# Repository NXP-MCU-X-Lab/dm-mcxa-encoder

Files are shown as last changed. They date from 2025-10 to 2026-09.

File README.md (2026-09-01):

# NXP MCXA344 Dual-Track Inductive Encoder

> English | [中文](README.zh-CN.md)

Firmware for the HW_V2 dual-track inductive absolute encoder based on the NXP
MCXA344. It samples 16/15 Vernier tracks at 10 kHz and provides a native 16-bit
single-turn position through a 2.5 Mbit/s T-Format interface.

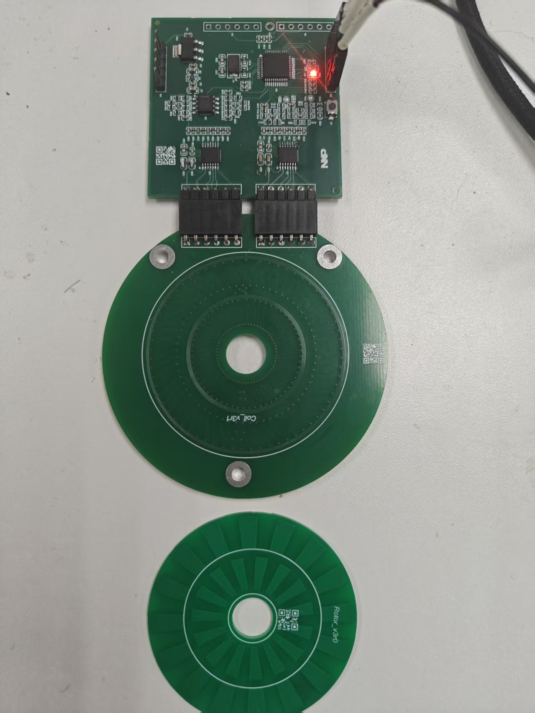
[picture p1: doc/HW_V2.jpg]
HW_V2 inductive encoder hardware


## Features

- 16/15 Vernier single-turn absolute-angle solver
- Native 16-bit position output (`0..65535` counts per revolution)
- Per-track offset, gain, quadrature, and ellipse correction
- Runtime center and gain adaptation with automatic persistence
- Branch validation, last-valid-position hold, and controlled re-lock
- Standard T-Format ID0/1/2/3/6/7/8/C/D responder on LPUART2/eDMA
- Persistent zero position and 762-byte paged encoder EEPROM image
- Compact FreeMASTER status and service page on LPUART0
- DWT execution profiling and dual-ADC sample-pair diagnostics

## Hardware

| Item | Configuration |
| --- | --- |
| MCU | NXP MCXA344VLL, Cortex-M33 with FPU, 180 MHz |
| Analog front end | MCXA OPAMP0/1 and external TLV9062 |
| Sampling | LPADC0/1, four channels, CTIMER0 trigger, 10 kHz |
| Persistent storage | Two 8 KB Flash sectors, 1024-byte snapshots, sequence and CRC32 |
| FreeMASTER | LPUART0, 115200 baud, 8N1 |
| T-Format | LPUART2, 2,500,000 baud, 8N1 |

### Signal Wiring

| Signal | MCU connection |
| --- | --- |
| A1 SIN | OPAMP0_OUT -> P2_15 (ADC0_A2) |
| A1 COS | OPAMP1_OUT -> P2_19 (ADC1_A2) |
| A2 SIN | TLV9062 output -> P2_6 (ADC1_A3) |
| A2 COS | TLV9062 output -> P2_7 (ADC0_A7) |
| T-Format TX | P2_2, LPUART2_TXD |
| T-Format RX | P2_3, LPUART2_RXD |
| RS-485 direction | P3_12, `DIR_485`; low for receive, high for transmit |
| Main-loop heartbeat | P3_11 |
| ADC ISR timing probe | P3_0 |

## Repository Layout

```text
source/
  app_adc.{h,c}              Synchronized dual-LPADC sampling
  app_encoder.{h,c}          Hardware-independent encoder algorithm
  app_encoder_runtime.{h,c}  Runtime adaptation, commands, and persistence
  app_encoder_storage.{h,c}  Dual-sector snapshots and CRC32
  app_encoder_defaults.c     Board default calibration
  app_tformat.{h,c}          T-Format responder on LPUART2/eDMA
  app_freemaster.{h,c}       FreeMASTER initialization and TSA table
  hardware_init.{h,c}        Clocks, OPAMP, pins, and utility GPIO

tools/
  tformat_test.py            Standard T-Format Python host

tests/
  encoder_sim.c              Algorithm and dynamic-profile simulation
  tformat_sim.c              Protocol vectors and state-machine tests
  storage_sim.c              Flash snapshot and power-loss injection tests
  stubs/                     Minimal MCU headers so app_tformat.c builds on the host

freemaster/
  index.html                 Compact operator and service page
  digital_encoder.pmpx       FreeMASTER desktop project
```

## Build and Flash

Install Keil MDK with ARMCLANG 6.23 and `NXP.MCXA344_DFP.25.06.00`. Open
`ind_encoder.uvprojx` and build target `ind_encoder`, or run:

```powershell
C:\Keil_v5\UV4\uVision.com -b ind_encoder.uvprojx -t ind_encoder -j0
```

The project targets `MCXA344VLL` and uses the `MCXA34X_256.FLM` download
algorithm. The application image is limited to `0x00000000..0x0003BFFF`.
`0x0003C000..0x0003FFFF` is reserved for persistent encoder data.

## T-Format Interface

The responder follows the public [NXP T-Format definitions](https://github.com/nxp-mcuxpresso/mcuxsdk-core/blob/release/26.03.00-pvw2/drivers/flexio/t-format/fsl_flexio_t-format.h)
and the field layout documented by the [TI T-Format reference design](https://www.ti.com/lit/ug/tidue74f/tidue74f.pdf).

| ID | CF | Function | Response length |
| --- | --- | --- | --- |
| ID0 | `0x02` | Single-turn position | 6 bytes |
| ID1 | `0x8A` | Multi-turn field, fixed to 0 | 6 bytes |
| ID2 | `0x92` | Encoder ID, `ENID=0x10` | 4 bytes |
| ID3 | `0x1A` | Position, ENID, ABM, and ALMC | 11 bytes |
| ID6 | `0x32` | EEPROM write | 4 bytes |
| ID7 | `0xBA` | Error reset | 6 bytes |
| ID8 | `0xC2` | Set and save single-turn zero | 6 bytes |
| IDC | `0x62` | Multi-turn reset acknowledgement; ABM remains 0 | 6 bytes |
| IDD | `0xEA` | EEPROM read | 4 bytes |

Every CF byte above is derived, not copied: `sink code 2 | (ID << 3) | (odd parity of
the ID bits << 7)`. Frame lengths, the ALMC bit map, the SF encoder-error field, the
ADF address/busy masks and the CRC polynomial all match the NXP definitions linked
above. `ENID` is the one value that does not come from a specification -- `0x10` is a
placeholder and must be agreed with the drive, since the resolution the drive infers
depends on it.

The UART is `2,500,000 baud, 8N1, idle high, LSB first`. `ABS0/ABS1` contain
the native 16-bit count and `ABS2=0`. Multi-turn fields are always zero. CRC uses
polynomial `x^8 + 1` with initial value 0. Invalid or stale position data is held
at the last valid value and reported as Counting Error through SF and ALMC.

`SF.ea0` reports Counting Error, `SF.ca0` reports a CF parity error, and
`SF.ca1` reports a UART delimiter error. `ALMC.CE` reports invalid or stale
position data and `ALMC.OS` reports speeds above 7200 rpm. Unsupported sensor
alarms remain zero. Communication errors are latched until a valid ID7 reset;
an active position fault is asserted again immediately.

ID7, ID8, and IDC execute after ten consecutive identical requests separated by
at least 40 us. ID8 saves the single-turn zero only when the shaft is stationary;
a rejected sequence reports Counting Error and is not deferred.

ADF address `0x7F` selects a volatile EEPROM page. Pages 0-5 each expose
127 persistent bytes (`0x00..0x7E`), for 762 bytes total. Pages 6 and 7 read as
`0xFF` and ignore writes. A data write keeps ADF busy until the new Flash
snapshot is verified; while busy, reads and writes return `EDF=0` and a second
write is rejected. Configuration writes require a stationary shaft. Unsupported
control fields and EEPROM CRC errors are silently ignored, and the protocol UART
emits no unsolicited text.

### Python Host

Install pyserial and replace `COM78` with the connected adapter:

```powershell
python -m pip install pyserial
python tools\tformat_test.py --self-test
python tools\tformat_test.py --port COM78 --data-id 0 --count 1000 --verbose
python tools\tformat_test.py --port COM78 --data-id 3 --count 1000
python tools\tformat_test.py --port COM78 --reset position
python tools\tformat_test.py --port COM78 --page 0 --eeprom-write 0x20 0xA5
python tools\tformat_test.py --port COM78 --page 0 --eeprom-read 0x20
python tools\tformat_test.py --port COM78 --page 0 --eeprom-read-page
python tools\tformat_test.py --port COM78 --eeprom-read-all
python tools\tformat_test.py --port COM78 --page 0 --eeprom-write-page page0.bin
```

`--reset` sends the required ten-frame sequence. A page image is a raw 127-byte
binary file; full-page writes skip unchanged bytes and verify the final page.

## Calibration and Operation

At startup, the latest valid Flash snapshot is loaded. If storage is empty, the
encoder starts from board defaults, adapts track centers and gains after adequate
rotational coverage, and saves the converged parameters after the shaft becomes
stationary. T-Format reports Counting Error until this initial adaptation locks.

`Zero & Save` and T-Format ID8 require the position to remain within 16 counts
for 0.5 seconds. The firmware averages 64 samples, changes the single-turn zero,
and confirms completion only after Flash verification.

The complete ellipse and quadrature calibration remains available in the
FreeMASTER Service section. It captures 8192 decimated samples while the shaft
is rotated through complete cycles, then saves the solved calibration and zero.

## FreeMASTER

Open `freemaster/digital_encoder.pmpx`, connect LPUART0 at 115200 baud, and open
the embedded web page. The main view contains readiness, angle, speed, status,
and `Zero & Save`. The collapsed Service section contains raw ADC values,
runtime counters, T-Format counters, factory calibration, and configuration
erase. The page polls primary status at approximately 4 Hz and does not use
Scope or Recorder.

## Configuration

| Macro | Value | Purpose |
| --- | --- | --- |
| `ADC_SAMPLE_RATE_HZ` | `10000` | Encoder update rate |
| `ENCODER_CAL_SAMPLE_COUNT` | `8192` | Service calibration samples |
| `ENCODER_TRACKING_BW_HZ` | `100.0f` | Observer bandwidth |
| `ENCODER_TRACKING_ZETA` | `0.707f` | Observer damping ratio |
| `ENCODER_FILTER_HOLD_RESYNC_SAMPLES` | `50` | Re-lock interval after invalid samples |
| `ENCODER_OUTPUT_DEADBAND_DEG` | `0.015f` | Monitoring-angle dead band |
| `ENCODER_ANGLE_COUNT_HYSTERESIS` | `3` | Low-latency count hysteresis |

## Notes

- The product interface is single-turn; ABM and all multi-turn fields are zero.
- The current storage version does not migrate older records. Run Factory Cal
  once after installing firmware that changes the persistent record version.
- Flash erase/program temporarily pauses sampling and T-Format responses.
- EEPROM and zero writes remain busy until the shaft is stationary and the new
  snapshot is verified.
- LPUART0 is reserved for FreeMASTER. DebugConsole and ordinary UART logs are
  not part of the product target.

## License

The project application code is provided under the BSD-3-Clause license; see
[LICENSE](LICENSE). Bundled SDK, CMSIS, and FreeMASTER components retain their
own copyright and license notices.

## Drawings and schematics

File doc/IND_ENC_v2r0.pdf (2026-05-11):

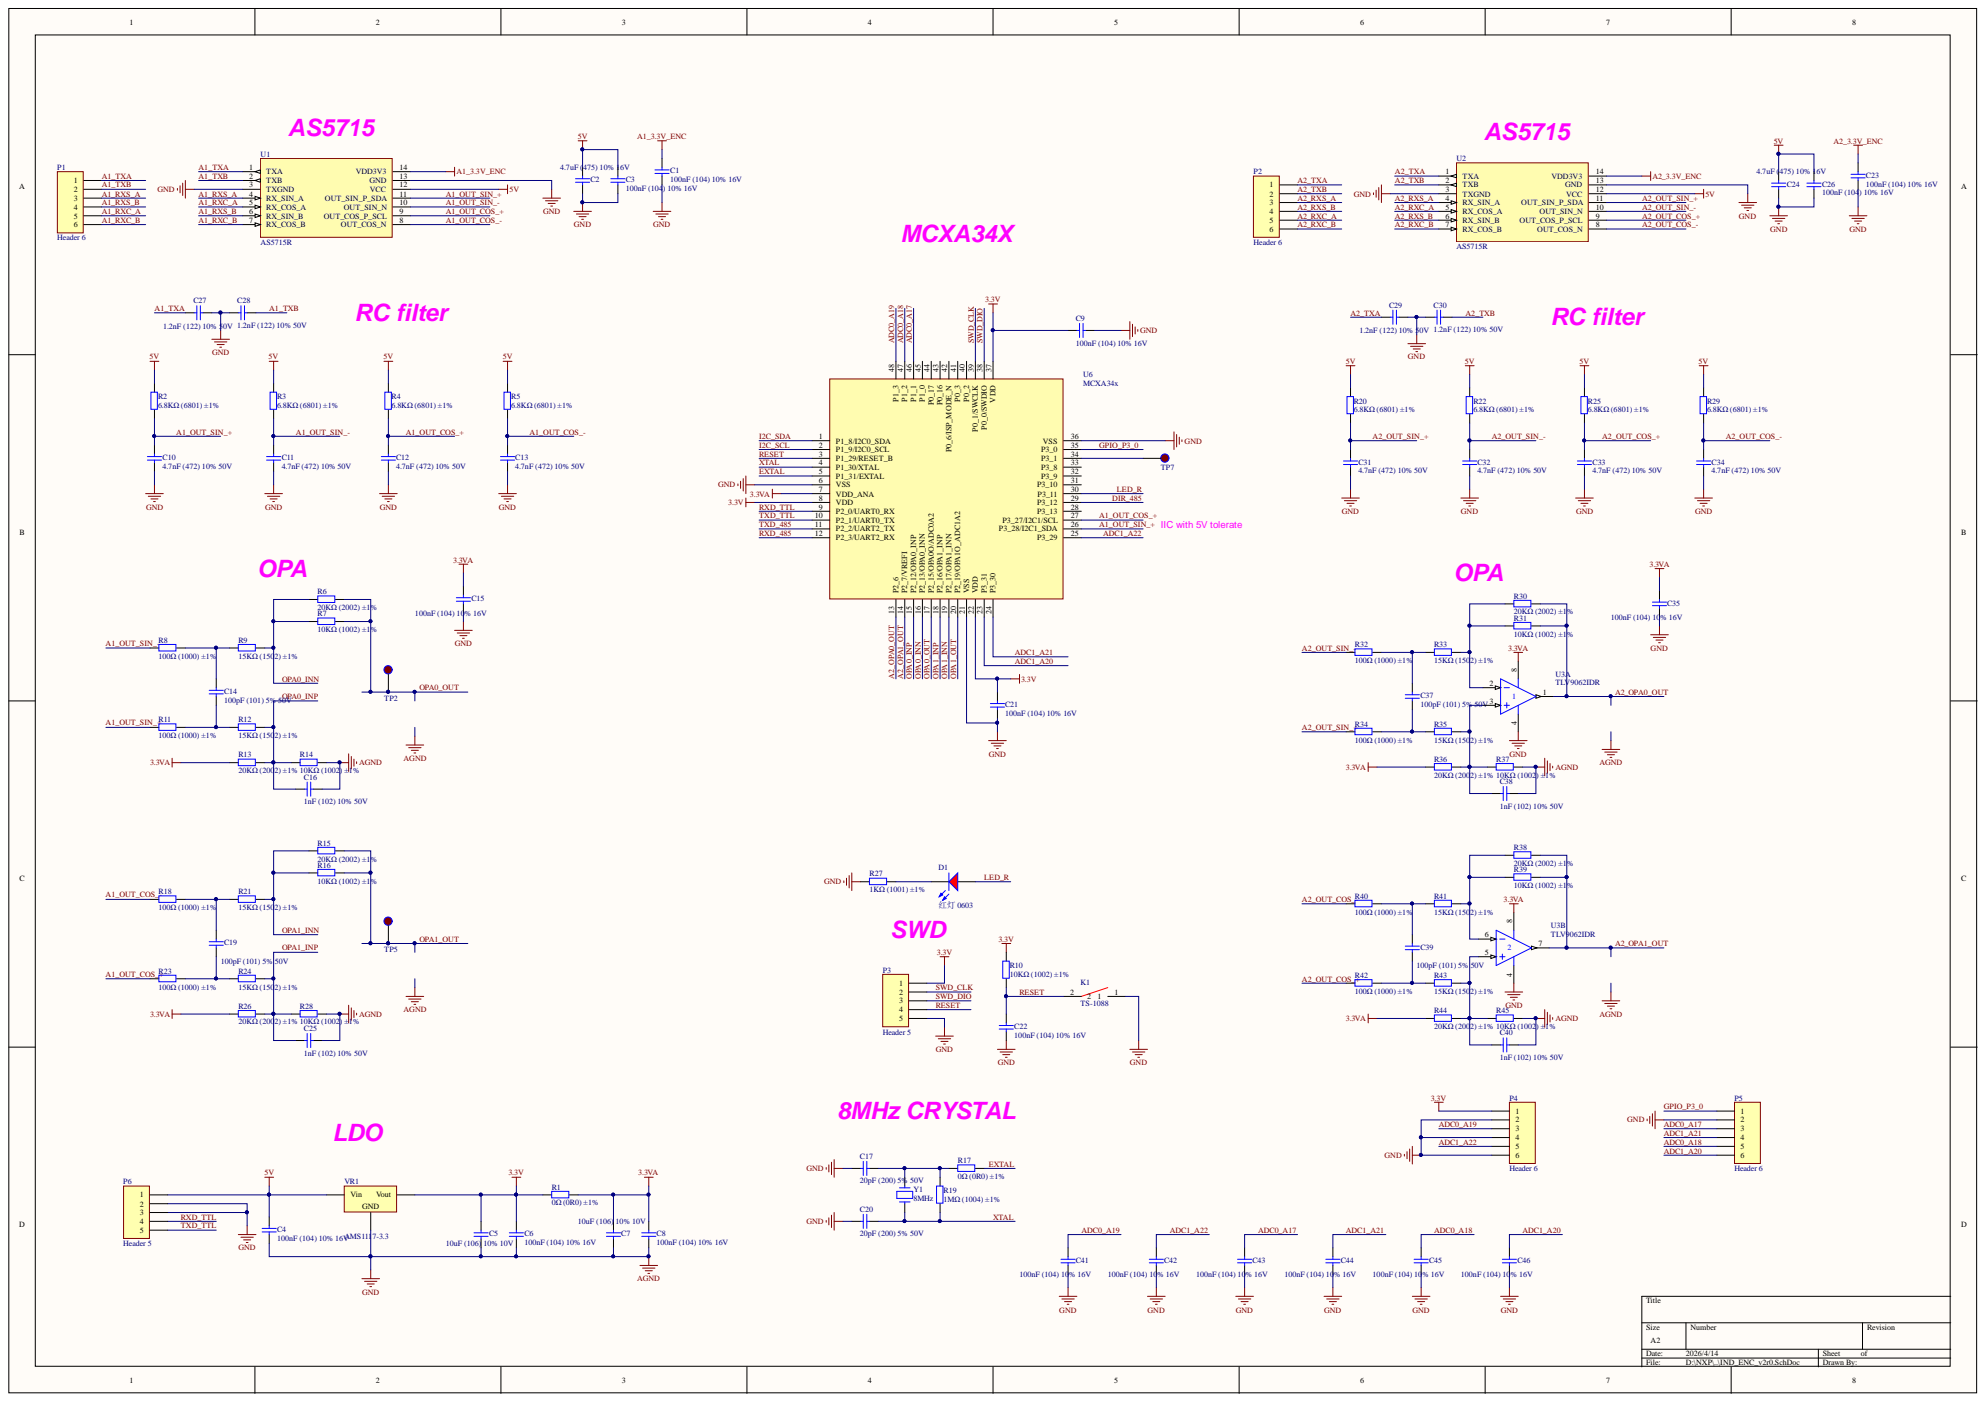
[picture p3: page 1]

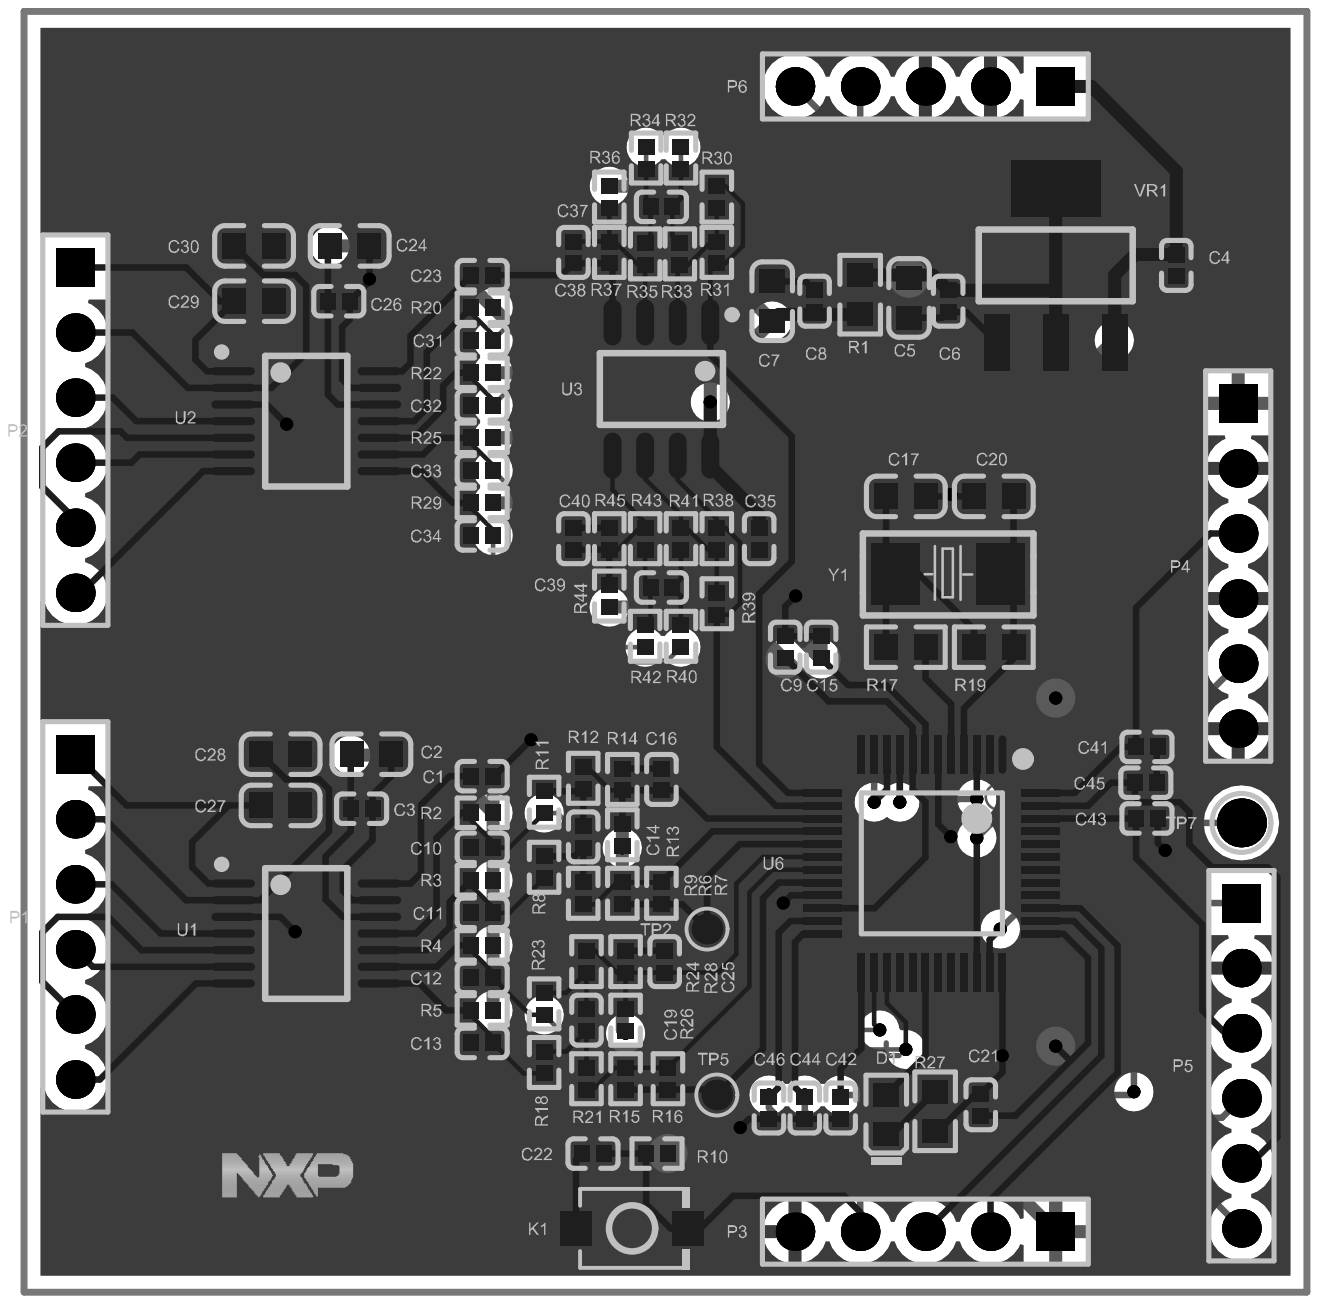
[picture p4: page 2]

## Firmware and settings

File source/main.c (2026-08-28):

/*
  * Copyright 2025 NXP
  *
  * SPDX-License-Identifier: BSD-3-Clause
  */

#include "fsl_common.h"

#include "app_adc.h"
#include "app_encoder_runtime.h"
#include "app_freemaster.h"
#include "app_tformat.h"
#include "freemaster.h"
#include "freemaster_cfg.h"
#include "freemaster_serial_lpuart.h"
#include "hardware_init.h"

static void run_main_loop(void)
{
    while (1)
    {
        EncoderApp_Service();
        FMSTR_Poll();
        Heartbeat_Service();
        __WFI();
    }
}

int main(void)
{
    Hardware_Init();
    adc_init();
    AppFreemaster_Init();
    TFormat_Init();
    EncoderApp_Init();

    run_main_loop();
}

#if FMSTR_SHORT_INTR || FMSTR_LONG_INTR

void LPUART0_IRQHandler(void)
{
    FMSTR_SerialIsr();
}

#endif

void HardFault_Handler(void)
{
    while (1)
    {
    }
}

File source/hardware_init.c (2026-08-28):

/*
  * Copyright 2025 NXP
  *
  * SPDX-License-Identifier: BSD-3-Clause
  */
/*${header:start}*/
#include "pin_mux.h"
#include "fsl_clock.h"
#include "fsl_reset.h"
#include "fsl_spc.h"
#include "fsl_opamp.h"
#include "fsl_gpio.h"
#include "fsl_port.h"
#include "fsl_mau.h"
#include "clock_config.h"
#include "hardware_init.h"
/*${header:end}*/





/* Test pin for ADC timing measurement (P3_0, driven low while ISR is busy) */
#define TEST_PIN_GPIO       GPIO3
#define TEST_PIN_PORT       PORT3
#define TEST_PIN_NUM        0U

#define HEARTBEAT_GPIO      GPIO3
#define HEARTBEAT_PORT      PORT3
#define HEARTBEAT_PIN       11U
#define HEARTBEAT_TOGGLE_INTERVAL_MS 100U

#define DEMO_OPAMP_COMP_CAP       kOPAMP_FitGain2x
#define DEMO_OPAMP_BIAS_CURRENT   kOPAMP_NoChange



/*! @brief Initialize TEST pin (P3_0) for ADC timing measurement */
void TestPin_Init(void)
{
    gpio_pin_config_t pin_config = {
        .pinDirection = kGPIO_DigitalOutput,
        .outputLogic = 1  /* Idle high; ISR drives low while busy */
    };

    PORT_SetPinMux(TEST_PIN_PORT, TEST_PIN_NUM, kPORT_MuxAsGpio);
    GPIO_PinInit(TEST_PIN_GPIO, TEST_PIN_NUM, &pin_config);
}

/* Free-running millisecond tick incremented by SysTick (configured @ 1 kHz).
 * Used by delay_ms() — independent of SDK_DelayAtLeastUs(), which has been
 * observed to skip its busy-wait on this part. */
volatile uint32_t g_systick_ms = 0U;

void Heartbeat_Init(void)
{
    gpio_pin_config_t pin_config = {
        .pinDirection = kGPIO_DigitalOutput,
        .outputLogic = 0
    };
    PORT_SetPinMux(HEARTBEAT_PORT, HEARTBEAT_PIN, kPORT_MuxAsGpio);
    GPIO_PinInit(HEARTBEAT_GPIO, HEARTBEAT_PIN, &pin_config);
    uint32_t core_hz = CLOCK_GetFreq(kCLOCK_CoreSysClk);
    SysTick_Config(core_hz / 1000U);
}

void SysTick_Handler(void)
{
    g_systick_ms++;
}

void Heartbeat_Service(void)
{
    static uint32_t last_toggle_ms;
    const uint32_t now = g_systick_ms;

    if ((uint32_t)(now - last_toggle_ms) >= HEARTBEAT_TOGGLE_INTERVAL_MS)
    {
        last_toggle_ms = now;
        GPIO_PortToggle(HEARTBEAT_GPIO, 1U << HEARTBEAT_PIN);
    }
}

void delay_ms(uint32_t ms)
{
    uint32_t t0 = g_systick_ms;
    while ((uint32_t)(g_systick_ms - t0) < ms)
    {
        /* spin */
    }
}

/*! @brief Configure OPAMP modules */
void Opamp_Init(void)
{
    opamp_config_t config;

    RESET_ReleasePeripheralReset(kOPAMP0_RST_SHIFT_RSTn);
    RESET_ReleasePeripheralReset(kOPAMP1_RST_SHIFT_RSTn);

    SPC_EnableActiveModeAnalogModules(SPC0, (kSPC_controlOpamp0 | kSPC_controlOpamp1));
    
    OPAMP_GetDefaultConfig(&config);
    config.compCap     = DEMO_OPAMP_COMP_CAP;
    config.biasCurrent = DEMO_OPAMP_BIAS_CURRENT;
    config.enable = true;
    
    OPAMP_Init(OPAMP0, &config);
    OPAMP_Init(OPAMP1, &config);
    
    OPAMP_Enable(OPAMP0, true);
    OPAMP_Enable(OPAMP1, true);
}

/*${function:start}*/
void Hardware_Init(void)
{
    Pins_Init();
    BOARD_InitBootClocks();
    Opamp_Init();
    TestPin_Init();
    Heartbeat_Init();
    
    mau_config_t cfg;
    MAU_GetDefaultConfig(&cfg);
    MAU_Init(MAU0, &cfg);
}

/*! @brief Set test pin to high level */
void TestPin_Set(void)
{
    GPIO_PinWrite(TEST_PIN_GPIO, TEST_PIN_NUM, 1U);
}

/*! @brief Set test pin to low level */
void TestPin_Clear(void)
{
    GPIO_PinWrite(TEST_PIN_GPIO, TEST_PIN_NUM, 0U);
}

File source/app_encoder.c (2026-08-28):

#include "app_encoder.h"
#include "app_adc.h"

#include <float.h>
#include <math.h>
#include <stddef.h>

#define ENCODER_PI (3.14159265358979323846f)
#define ENCODER_ADC_RAIL_LOW (64U)
#define ENCODER_ADC_RAIL_HIGH (65471U)
#define ENCODER_MIN_RAW_AMPLITUDE (256.0f)
#define ENCODER_MIN_NORMALIZED_MAG (0.15f)
#define ENCODER_TRACK_PHASE_TOLERANCE_DEG (45.0f)
#define ENCODER_DEFAULT_RAW_CENTER (32768.0f)
#define ENCODER_DEFAULT_RAW_AMPLITUDE (16384.0f)
#define ENCODER_FINE_BRANCH_STEP_DEG (360.0f / (float)ENCODER_TRACK16_CYCLES)
#define ENCODER_BRANCH_SLIP_STEP_DEG (0.5f * ENCODER_FINE_BRANCH_STEP_DEG)
#define ENCODER_BRANCH_ERROR_MARGIN_DEG (5.0f)
/* Acceptance band for trimming: exactly the set of magnitudes the gain authority
 * can still pull back to 1.0. Gain is multiplicative -- a delta d scales T by
 * (1 + d) -- so the band is not symmetric about 1.0. With a limit of L, a
 * magnitude m is correctable when 1/(1 + L) <= m <= 1/(1 - L).
 *
 * Getting this wrong in either direction is a trap. Narrower than the authority
 * (the original 0.75..1.25 against +/-0.5) leaves half of it unreachable: the
 * estimator switches itself off precisely when the amplitude has drifted far
 * enough to need it, and can never climb back. Wider than the authority admits
 * magnitudes it cannot fix, so the AGC parks against its clamp. The rail and
 * WEAK checks alongside are what actually reject unusable samples. */
#define ENCODER_RUNTIME_TRIM_MAG_MIN (1.0f / (1.0f + ENCODER_RUNTIME_TRIM_GAIN_TOTAL_LIMIT))
#define ENCODER_RUNTIME_TRIM_MAG_MAX (1.0f / (1.0f - ENCODER_RUNTIME_TRIM_GAIN_TOTAL_LIMIT))
#define ENCODER_RUNTIME_TRIM_BIN_COUNT (16U)
#define ENCODER_RUNTIME_TRIM_FULL_COVERAGE_MASK (0xFFFFUL)
#define ENCODER_RUNTIME_TRIM_MIN_WINDOW_SAMPLES (512U)
#define ENCODER_RUNTIME_TRIM_ALPHA (0.125f)
/* 5 s at 10 kHz. Long enough that ordinary rough running never re-acquires,
 * short enough that a board which locked on bad data heals itself instead of
 * needing a reflash. */
#define ENCODER_RUNTIME_TRIM_RELOCK_SAMPLES (50000U)
/* Windows that still take the measured centre outright rather than creeping.
 * The first lock is necessarily approximate -- harmonic distortion makes the
 * waveform asymmetric, so the min/max midpoint sits a few hundred counts off the
 * true centre even across whole cycles. Creeping that away at the drift step
 * limit would take hundreds of revolutions; a few more snap windows close it in
 * a few. Only once those are spent is the remaining error actually drift. */
#define ENCODER_RUNTIME_TRIM_SNAP_SOLVES (4U)

typedef struct _encoder_solver_candidate
{
    float p16;
    float p15;
    float coarse;
    float angle;
    float phase16_error;
    float phase15_error;
    float error;
} encoder_solver_candidate_t;

static bool is_finite_float(float value)
{
    return ((value == value) && (fabsf(value) < FLT_MAX));
}

static float wrap_deg(float deg)
{
    while (deg >= 360.0f)
    {
        deg -= 360.0f;
    }

    while (deg < 0.0f)
    {
        deg += 360.0f;
    }

    return deg;
}

static float signed_angle_error_deg(float actual, float expected)
{
    float diff = wrap_deg(actual - expected);

    if (diff > 180.0f)
    {
        diff -= 360.0f;
    }

    return diff;
}

static float max_float(float a, float b)
{
    return (a > b) ? a : b;
}

static uint32_t angle_to_counts(float angle_deg)
{
    uint32_t counts = (uint32_t)(((wrap_deg(angle_deg) * (float)ENCODER_COUNTS_PER_REV) / 360.0f) + 0.5f);

    if (counts >= ENCODER_COUNTS_PER_REV)
    {
        counts -= ENCODER_COUNTS_PER_REV;
    }

    return counts;
}

static float clamp_float(float value, float min_value, float max_value)
{
    if (value < min_value)
    {
        return min_value;
    }

    if (value > max_value)
    {
        return max_value;
    }

    return value;
}

/* Type-II tracking observer (software PLL) — canonical resolver / inductive
 * encoder output stage. Closed-loop characteristic eq: s^2 + Kp*s + Ki,
 * Kp = 2*zeta*wn, Ki = wn^2. Precomputed at compile time for the fixed
 * 10 kHz ADC sample rate to keep the hot path branch-free. */
#define ENCODER_TRACKING_DT      (1.0f / (float)ADC_SAMPLE_RATE_HZ)
#define ENCODER_TRACKING_WN      (2.0f * ENCODER_PI * ENCODER_TRACKING_BW_HZ)
#define ENCODER_TRACKING_KP      (2.0f * ENCODER_TRACKING_ZETA * ENCODER_TRACKING_WN)
#define ENCODER_TRACKING_KI      (ENCODER_TRACKING_WN * ENCODER_TRACKING_WN)

static float filter_published_angle(encoder_state_t *state, float raw_angle_deg)
{
    float error;
    float predicted_angle;

    if (state == NULL)
    {
        return wrap_deg(raw_angle_deg);
    }

    if (!state->filter_initialized)
    {
        state->filtered_angle_deg = wrap_deg(raw_angle_deg);
        state->tracking_velocity_dps = 0.0f;
        state->filter_initialized = true;
        return state->filtered_angle_deg;
    }

    predicted_angle = wrap_deg(state->filtered_angle_deg +
                               (state->tracking_velocity_dps * ENCODER_TRACKING_DT));
    error = signed_angle_error_deg(raw_angle_deg, predicted_angle);
    if (fabsf(error) > ENCODER_FILTER_RESYNC_ERROR_DEG)
    {
        state->tracking_velocity_dps = clamp_float(
            signed_angle_error_deg(raw_angle_deg, state->last_angle_raw_deg) / ENCODER_TRACKING_DT,
            -ENCODER_TRACKING_VEL_MAX_DPS,
            ENCODER_TRACKING_VEL_MAX_DPS);
        state->filtered_angle_deg = wrap_deg(raw_angle_deg);
        return state->filtered_angle_deg;
    }

    state->tracking_velocity_dps += ENCODER_TRACKING_KI * error * ENCODER_TRACKING_DT;
    state->tracking_velocity_dps = clamp_float(state->tracking_velocity_dps,
                                               -ENCODER_TRACKING_VEL_MAX_DPS,
                                               ENCODER_TRACKING_VEL_MAX_DPS);
    state->filtered_angle_deg = wrap_deg(predicted_angle +
                                         (ENCODER_TRACKING_KP * error * ENCODER_TRACKING_DT));
    return state->filtered_angle_deg;
}

static bool adc_is_rail(uint16_t raw)
{
    return ((raw <= ENCODER_ADC_RAIL_LOW) || (raw >= ENCODER_ADC_RAIL_HIGH));
}

static void set_identity_track_cal(encoder_track_calibration_t *track)
{
    if (track == NULL)
    {
        return;
    }

    track->center_sin = ENCODER_DEFAULT_RAW_CENTER;
    track->center_cos = ENCODER_DEFAULT_RAW_CENTER;
    track->t00 = 1.0f / ENCODER_DEFAULT_RAW_AMPLITUDE;
    track->t10 = 0.0f;
    track->t11 = 1.0f / ENCODER_DEFAULT_RAW_AMPLITUDE;
}

static void init_track_stats(encoder_track_cal_stats_t *stats)
{
    *stats = (encoder_track_cal_stats_t){0};
    stats->min_sin = UINT16_MAX;
    stats->min_cos = UINT16_MAX;
}

static void update_min_max(uint16_t raw, uint16_t *min_raw, uint16_t *max_raw)
{
    if (raw < *min_raw)
    {
        *min_raw = raw;
    }

    if (raw > *max_raw)
    {
        *max_raw = raw;
    }
}
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

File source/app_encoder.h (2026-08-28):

#ifndef APP_ENCODER_H_
#define APP_ENCODER_H_

#include <stdbool.h>
#include <stdint.h>

#define ENCODER_TRACK16_CYCLES (16U)
#define ENCODER_TRACK15_CYCLES (15U)
#define ENCODER_CAL_SAMPLE_COUNT (8192U)
#define ENCODER_COUNTS_PER_REV (65536U)

#define ENCODER_STATUS_OK (0UL)
#define ENCODER_STATUS_NOT_CALIBRATED (1UL << 0)
#define ENCODER_STATUS_TRACK16_WEAK (1UL << 1)
#define ENCODER_STATUS_TRACK15_WEAK (1UL << 2)
#define ENCODER_STATUS_ADC_RAIL (1UL << 3)
#define ENCODER_STATUS_TRACK_MISMATCH (1UL << 4)
#define ENCODER_STATUS_CAL_FAILED (1UL << 5)
#define ENCODER_STATUS_HOLD_LAST (1UL << 6)
#define ENCODER_STATUS_CAL_STORAGE_INVALID (1UL << 7)
#define ENCODER_STATUS_FACTORY_CAL_REQUIRED (1UL << 8)

/* The bits that mean "this sample's position is untrustworthy", as opposed to
 * "this board has never been through a factory step". Only the former may
 * invalidate an output sample: a board running on compiled-in defaults carries
 * CAL_STORAGE_INVALID | FACTORY_CAL_REQUIRED for its entire life, and folding
 * those in made every never-calibrated board report a permanent fault -- including
 * long after the online estimator had converged to full accuracy. */
#define ENCODER_STATUS_POSITION_INVALID_MASK                                   \
    (ENCODER_STATUS_NOT_CALIBRATED | ENCODER_STATUS_TRACK16_WEAK |             \
     ENCODER_STATUS_TRACK15_WEAK | ENCODER_STATUS_ADC_RAIL |                   \
     ENCODER_STATUS_TRACK_MISMATCH | ENCODER_STATUS_CAL_FAILED |               \
     ENCODER_STATUS_HOLD_LAST)

/* Type-II tracking observer (software PLL) for published angle, matching the
 * canonical resolver-to-digital converter loop (AD2S1210 / TI SPRAA94 / etc.).
 * - BW   sets closed-loop bandwidth in Hz.
 * - ZETA sets damping ratio (0.707 = Butterworth, no overshoot).
 * Kp/Ki are precomputed from BW, ZETA, and the ADC sample period at compile time.
 * VEL_MAX_DPS clamps the velocity integrator to a physically plausible bound so
 * startup / glitch transients cannot wind it up. HOLD_RESYNC_SAMPLES forces a
 * re-lock if the signal has been invalid long enough that the stored position is
 * meaningless (LOS recovery, AD2S1210 style). */
#define ENCODER_TRACKING_BW_HZ      (100.0f)
#define ENCODER_TRACKING_ZETA       (0.707f)
#define ENCODER_TRACKING_VEL_MAX_DPS    (216000.0f)
#define ENCODER_FILTER_HOLD_RESYNC_SAMPLES (50U)

/* Branch-decision guards. Kept here with the rest of the tuning surface so the
 * host regression can assert against the real values rather than a copy.
 *
 * At 6000 rpm the shaft advances 3.6 deg/sample. Nine degrees admits an
 * instantaneous direction reversal plus model/noise margin; the 150 deg
 * fine-phase limit keeps 30 deg of distance from the Vernier branch boundary.
 *
 * CONFIDENCE_LIMIT is coupled to uncorrected harmonic content: |fine_delta| also
 * grows with distortion, so on a board with enough 3rd harmonic the guard starts
 * tripping on healthy samples. */
#define ENCODER_BRANCH_CONFIDENCE_LIMIT_DEG (150.0f)
#define ENCODER_MOTION_INNOVATION_LIMIT_DEG (9.0f)
#define ENCODER_FILTER_RESYNC_ERROR_DEG (9.0f)

/* How long the motion gate keeps vetoing after signal loss. The prediction is
 * extrapolated over the whole outage while the tolerance stays fixed, so its
 * uncertainty grows as 0.5*a*t^2 and eventually exceeds the 11.25 deg it would
 * need to tell one Vernier branch from another -- past that point the gate is no
 * longer discriminating, only delaying. Measured with `encoder_sim highspeed`:
 * at 2e6 deg/s^2 (0 to 6000 rpm in 18 ms) the gate still passes at 20 samples and
 * blocks at 30, so recovery stalls until the streak reaches this limit. Borrowing
 * the observer's 50-sample resync count made a 3 ms outage cost 5 ms of held
 * position. */
#define ENCODER_MOTION_INNOVATION_MAX_STREAK (20U)

/* Output hysteresis: if the new filtered angle is within this threshold of the
 * previously published angle, hold the previous value. Eliminates static jitter
 * without perturbing the PLL math. Industry standard approach (AS5048 / iC-MU
 * default 2–3 LSB on a 14-bit output, equivalent to 0.011–0.017° here).
 * Trade-off: motion below ~150 deg/s is reported in steps of the threshold. */
#define ENCODER_OUTPUT_DEADBAND_DEG (0.015f)

/* Output-stage hysteresis on the low-latency integer angle_counts: if the new
 * count differs from the last published one by at most this many LSBs in either
 * direction, hold the previous value. Float angle_deg remains the smooth
 * observer output used by monitoring and velocity estimation. */
#define ENCODER_ANGLE_COUNT_HYSTERESIS  (3)

/* Centre trim authority. Sized for board-to-board spread, not just drift: the
 * compiled-in defaults come from one board, and a centre that is wrong by a few
 * thousand counts destroys the angle rather than merely degrading it. The step
 * limit applies only after the first lock, where all that remains is thermal
 * drift -- acquisition takes the measured centre in one go. */
#define ENCODER_RUNTIME_TRIM_STEP_LIMIT_COUNTS (1.0f)
#define ENCODER_RUNTIME_TRIM_TOTAL_LIMIT_COUNTS (8192.0f)

/* AGC on T-matrix scale: drives the rotation-mean mag toward 1.0 to compensate
 * for analog amplitude drift between factory cal and runtime (temperature, OPAMP
 * gain, supply). Step limit caps per-revolution change; total limit prevents
 * runaway. +/-0.5 covers +/-50% amplitude drift.
 *
 * Note a common amplitude error is nearly harmless on its own -- it cancels in
 * atan2(sin, cos), measured at under 0.01 deg of extra error from 0.5x to 1.5x
 * (`encoder_sim bootstrap`). The AGC matters because magnitude is the health
 * signal everything else gates on, not because the angle needs it. */
#define ENCODER_RUNTIME_TRIM_GAIN_STEP_LIMIT  (0.02f)
#define ENCODER_RUNTIME_TRIM_GAIN_TOTAL_LIMIT (0.5f)

typedef struct _encoder_raw_sample
{
    uint16_t a1_sin_raw;
    uint16_t a1_cos_raw;
    uint16_t a2_sin_raw;
    uint16_t a2_cos_raw;
} encoder_raw_sample_t;

/* Lower-triangular ellipse correction: normalized = T * (raw - center).
 * The upper-right element is zero by Cholesky construction, so it is omitted. */
typedef struct _encoder_track_calibration
{
    float center_sin;
    float center_cos;
    float t00;
    float t10;
    float t11;
} encoder_track_calibration_t;

typedef struct _encoder_calibration
{
    encoder_track_calibration_t a1;
    encoder_track_calibration_t a2;
    float phase_a1_zero_deg;
    float phase_a2_zero_deg;
    bool valid;
} encoder_calibration_t;

typedef struct _encoder_cal_quality
{
    uint32_t sample_count;
    uint32_t status;
    float mag16;
    float mag15;
} encoder_cal_quality_t;
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

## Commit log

2025-10-24 第一版OK
2025-10-29 refine encoder demo
2025-11-09 update to alpha- beta filter
2025-11-28 refine on-line calibration
2026-05-11 add doc
    [Coil_v3r1.PcbDoc, IND_EC.SchDoc, IND_ENC_v1r0.PcbDoc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]
2026-05-11 remove V1
    [IND_EC.SchDoc, IND_ENC_v1r0.PcbDoc, IND_ENC_v1r0.PrjPCB]
2026-05-15 双道可以工作了,但是对校准敏感
    [IND_EC.SchDoc, IND_ENC_v1r0.PcbDoc, IND_ENC_v1r0.PrjPCB]
2026-05-18 算法OK
2026-05-18 flash 内部存储
2026-05-18 P3_10 P3_11一个测试,一个LED
2026-05-19 更新前端UI
2026-05-19 expose raw ADC channels for FreeMASTER scope
    Add adc_result global + TSA struct so the host can plot the four OPAMP
    outputs (a1_sin/cos_raw, a2_sin/cos_raw) directly in FreeMASTER's
    oscilloscope. Refreshed every ADC ISR.
2026-08-26 feat: add T-Format encoder output
2026-08-27 clean up doc
    [Coil_v3r1.PcbDoc, IND_ENC_v2r0.PcbDoc, IND_ENC_v2r0.PrjPCB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]
2026-08-27 feat(encoder): self-calibrating start-up, no factory step required
    A board that has never been calibrated now converges on its own from the
    compiled-in defaults, in about half a revolution, to the same accuracy as a
    factory-calibrated one. Measured with the new host harness.
    The online estimator could not previously do this because three gates all
    assumed a working encoder before letting the thing that makes it work run: the
    trim required a stored calibration, the ISR passed NULL for the baseline outside
    NVM mode, and the update required status == OK and a healthy magnitude. A board
    whose centre is wrong produces none of those. The centre is min/max, which needs
    only raw ADC samples.
    Acqui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
    [app_encoder.c, app_encoder.h, app_encoder_runtime.c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]
2026-08-28 feat: standard T-Format command set and dual-sector persistent storage
    The T-Format responder now uses the real control-field bytes instead of the
    placeholders it shipped with. They are not copied from a table: every CF derives
    as `sink code 2 | (ID << 3) | (odd parity of the ID bits << 7)`, and all nine
    come out exact. Checked against NXP's own master-side definitions in
    mcuxsdk-core drivers/flexio/t-format/fsl_flexio_t-format.h, which also confirms
    the frame lengths, the full ALMC bit map, the SF encoder-error field, the ADF
    address and busy masks, the CRC polynomial, and the reset ID-to-action mapping.
    ENID is now the only protocol value with no specification source; 0x10 remains a
    placeh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
    [app_adc.c, app_encoder.c, app_encoder.h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]
